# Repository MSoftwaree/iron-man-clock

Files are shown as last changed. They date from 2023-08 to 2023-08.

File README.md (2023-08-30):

# Iron man clock
This project is based on: https://www.thingiverse.com/thing:6063303

The repository was created due to the change of the script executing the program, the change of the LED ring, which made it necessary to change one element.
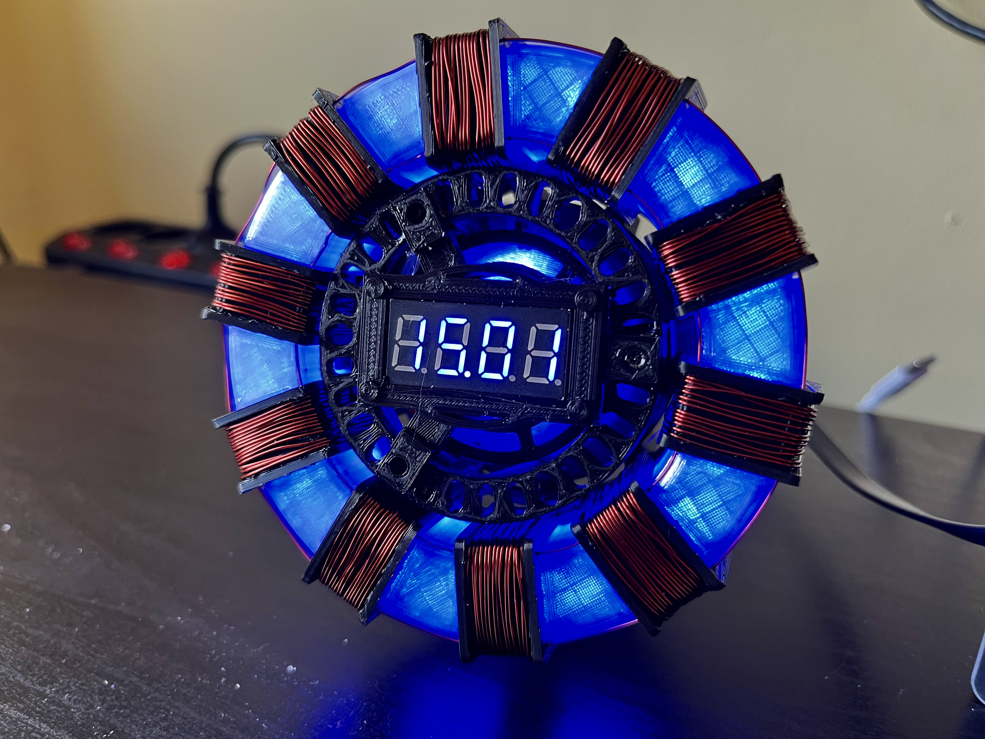
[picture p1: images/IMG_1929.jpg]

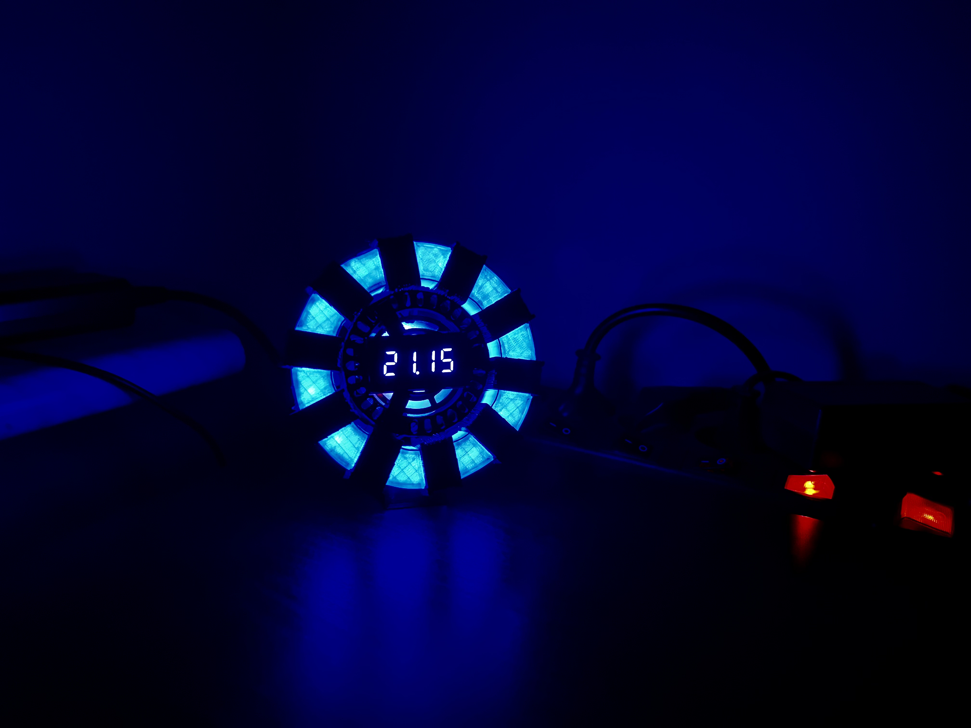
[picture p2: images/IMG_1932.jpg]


## List of components
- [Mini display 0.36'](https://pl.aliexpress.com/item/1005001566508703.html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)
- [RGB ring with 24 LEDs](https://pl.aliexpress.com/item/1005002287819725.html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)
- [D1 Mini ESP32](https://pl.aliexpress.com/item/1005001621844145.html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)
- Black and transparent filament for 3D printer
- Copper wire 0.5mm

## Changes in parts
I changed the LED ring to a smaller one due to availability in my country. As a result, its circumference decreased and did not fit the original parts. If you prefer to stay with the default number of LEDs (35 pieces), you can print as designed. However, if you prefer to change the number of LEDs to 24 pieces (as I did), it is necessary to print all elements at 95% of the size.

Then, however, there will be problems with two parts. Part_1 will not fit the size of the ESP32. Here I drilled a hole on one side to insert the button that blocked the mounting of the plate.

The second problem is with the display (Part_9), it will not fit the original item. As part of that, I redrawn it, widening the hole it's supposed to go in. You can find the STL file here: [Display clock holder](display_clock_holder.stl).

The rest of the parts are ok.

## Changes in code
The code has been changed due to incorrect operation and hard codes on the number of leds. I also wanted to make the code look cleaner.

The animations that occur every hour have also been changed (shown below) due to preference.

Link to original code: https://github.com/jejelinge/IRON_MAN_ARC_REACTOR

## Animations
### Clock startup
plot
### Every hour animation
plot

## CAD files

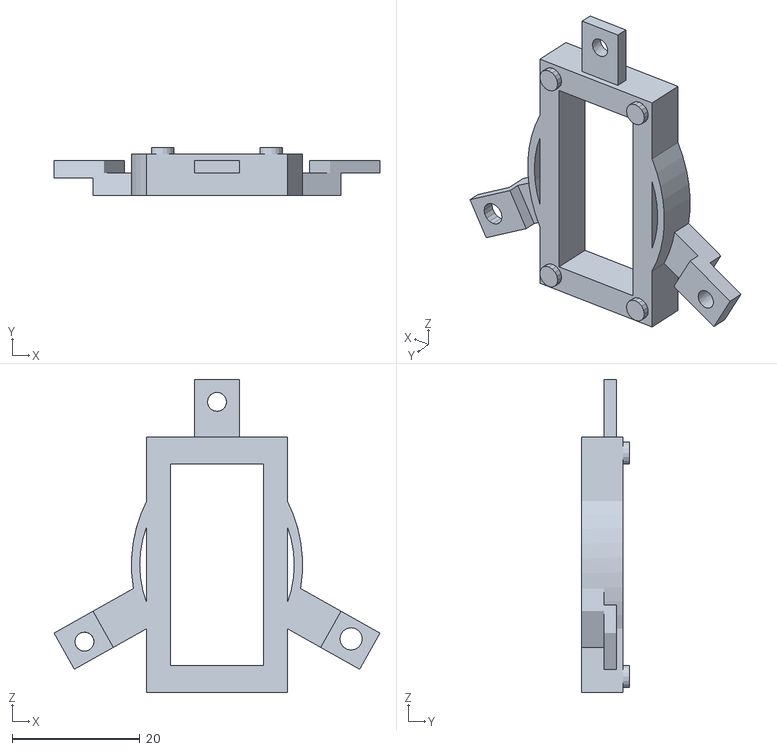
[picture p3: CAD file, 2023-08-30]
display_clock_holder.stl
51.0 x 7.50 x 49.0

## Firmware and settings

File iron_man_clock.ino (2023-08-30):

#include "Adafruit_NeoPixel.h"
#include "TM1637Display.h"
#include "NTPClient.h"
#include "WiFiManager.h"


// Blue LEDs variables
#define LED_PIN_1   25
#define LED_PIN_2   26

// RGB ring variables
#define PIN         17
#define NUMPIXELS   24
#define RED         00
#define GREEN       20
#define BLUE        255
#define RING_BRIGHTNESS 70

Adafruit_NeoPixel pixels(NUMPIXELS, PIN, NEO_GRB + NEO_KHZ800);

// Display variables
#define DISPLAY_CLK   18
#define DISPLAY_DIO   19
#define DISPLAY_BACKLIGHT   1

TM1637Display display(DISPLAY_CLK, DISPLAY_DIO);

// NTP Client initialization
const char *ssid     = "YOURS_SSID"; 
const char *password = "YOURS_PASSWORD";

int UTC = 2;
const long utcOffsetInSeconds = 3600;
int flag = 0;

WiFiUDP ntpUDP;
NTPClient timeClient(ntpUDP, "pool.ntp.org", utcOffsetInSeconds*UTC);


void setup() {
// Turn on Blue LEDs
  pinMode(LED_PIN_1, OUTPUT);
  pinMode(LED_PIN_2, OUTPUT);
  digitalWrite(LED_PIN_1, 1);
  digitalWrite(LED_PIN_2, 1);

// RGB ring initialization
  pixels.begin();
  pixels.setBrightness(RING_BRIGHTNESS);

// Turn on RGB ring
  ring_blue_light();

// Wifi connection
  WiFi.begin(ssid, password);
    while (WiFi.status() != WL_CONNECTED) {
    delay (500);
  }
  timeClient.begin();

// Display initialization
  display.setBrightness(DISPLAY_BACKLIGHT);

  uint8_t data[] = {0xff, 0xff, 0xff, 0xff};
  data[0] = display.encodeDigit(0);
  data[1] = display.encodeDigit(1);
  data[2] = display.encodeDigit(2);
  data[3] = display.encodeDigit(3);
  display.setSegments(data);
}

void loop() {
// Update the time on display
  timeClient.update();
  display.showNumberDecEx(timeClient.getHours(), 0x40, true, 2, 0);
  display.showNumberDecEx(timeClient.getMinutes(), 0, true, 2, 2);


// Animation every hour
  if(timeClient.getMinutes()== 00 && flag==0) {
    white_light_animation();
    flag=1;
  }
  if(timeClient.getMinutes()>=01) {
    flag=0;
  }

  ring_blue_light();
}

void ring_blue_light() {
  for(int i=0; i<NUMPIXELS; i++){
    pixels.setPixelColor(i, RED, GREEN, BLUE);
    pixels.show();
    delay(50);
  }
}

void white_light_animation() {
  int led_values[] = {0, 255, 0, 255};
  int values_count = 2;

  for(int i=0; i<NUMPIXELS; i++){
    pixels.setPixelColor(i, 255, 255, 255);
    pixels.show();
    delay(50);
  }

  for(int value=0; value<values_count; value++){
    for(int i=0; i<NUMPIXELS; i++){
      pixels.setPixelColor(i, led_values[value], led_values[value], led_values[value]);
      pixels.show();
    }
    delay(1000);
  }
  delay(4000);
}

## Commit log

2023-08-30 Add arduino script
2023-08-30 Add display holder
    [display_clock_holder.stl]
2023-08-30 Add link to STL file
